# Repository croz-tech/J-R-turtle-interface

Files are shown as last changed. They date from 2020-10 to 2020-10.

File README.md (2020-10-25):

# J-R-turtle-interface
Re-creation of the Jessop-Ralph turtle interface for the BBC Micro range of home computers.

Connects to the BBC Micro user port (20 way IDC) and the turtle via a 15 way D connector.
Requires a +5V stabilised power supply which can be taken from the BBC Micro's aux power output.  However this is often used for disk drives, therefore a seperate power supply can be used.  Interface and turtle are comatible with Acornsoft Logo (using the JESSOP) extension.  It can also be used with DART software or driven directly via user port commands.

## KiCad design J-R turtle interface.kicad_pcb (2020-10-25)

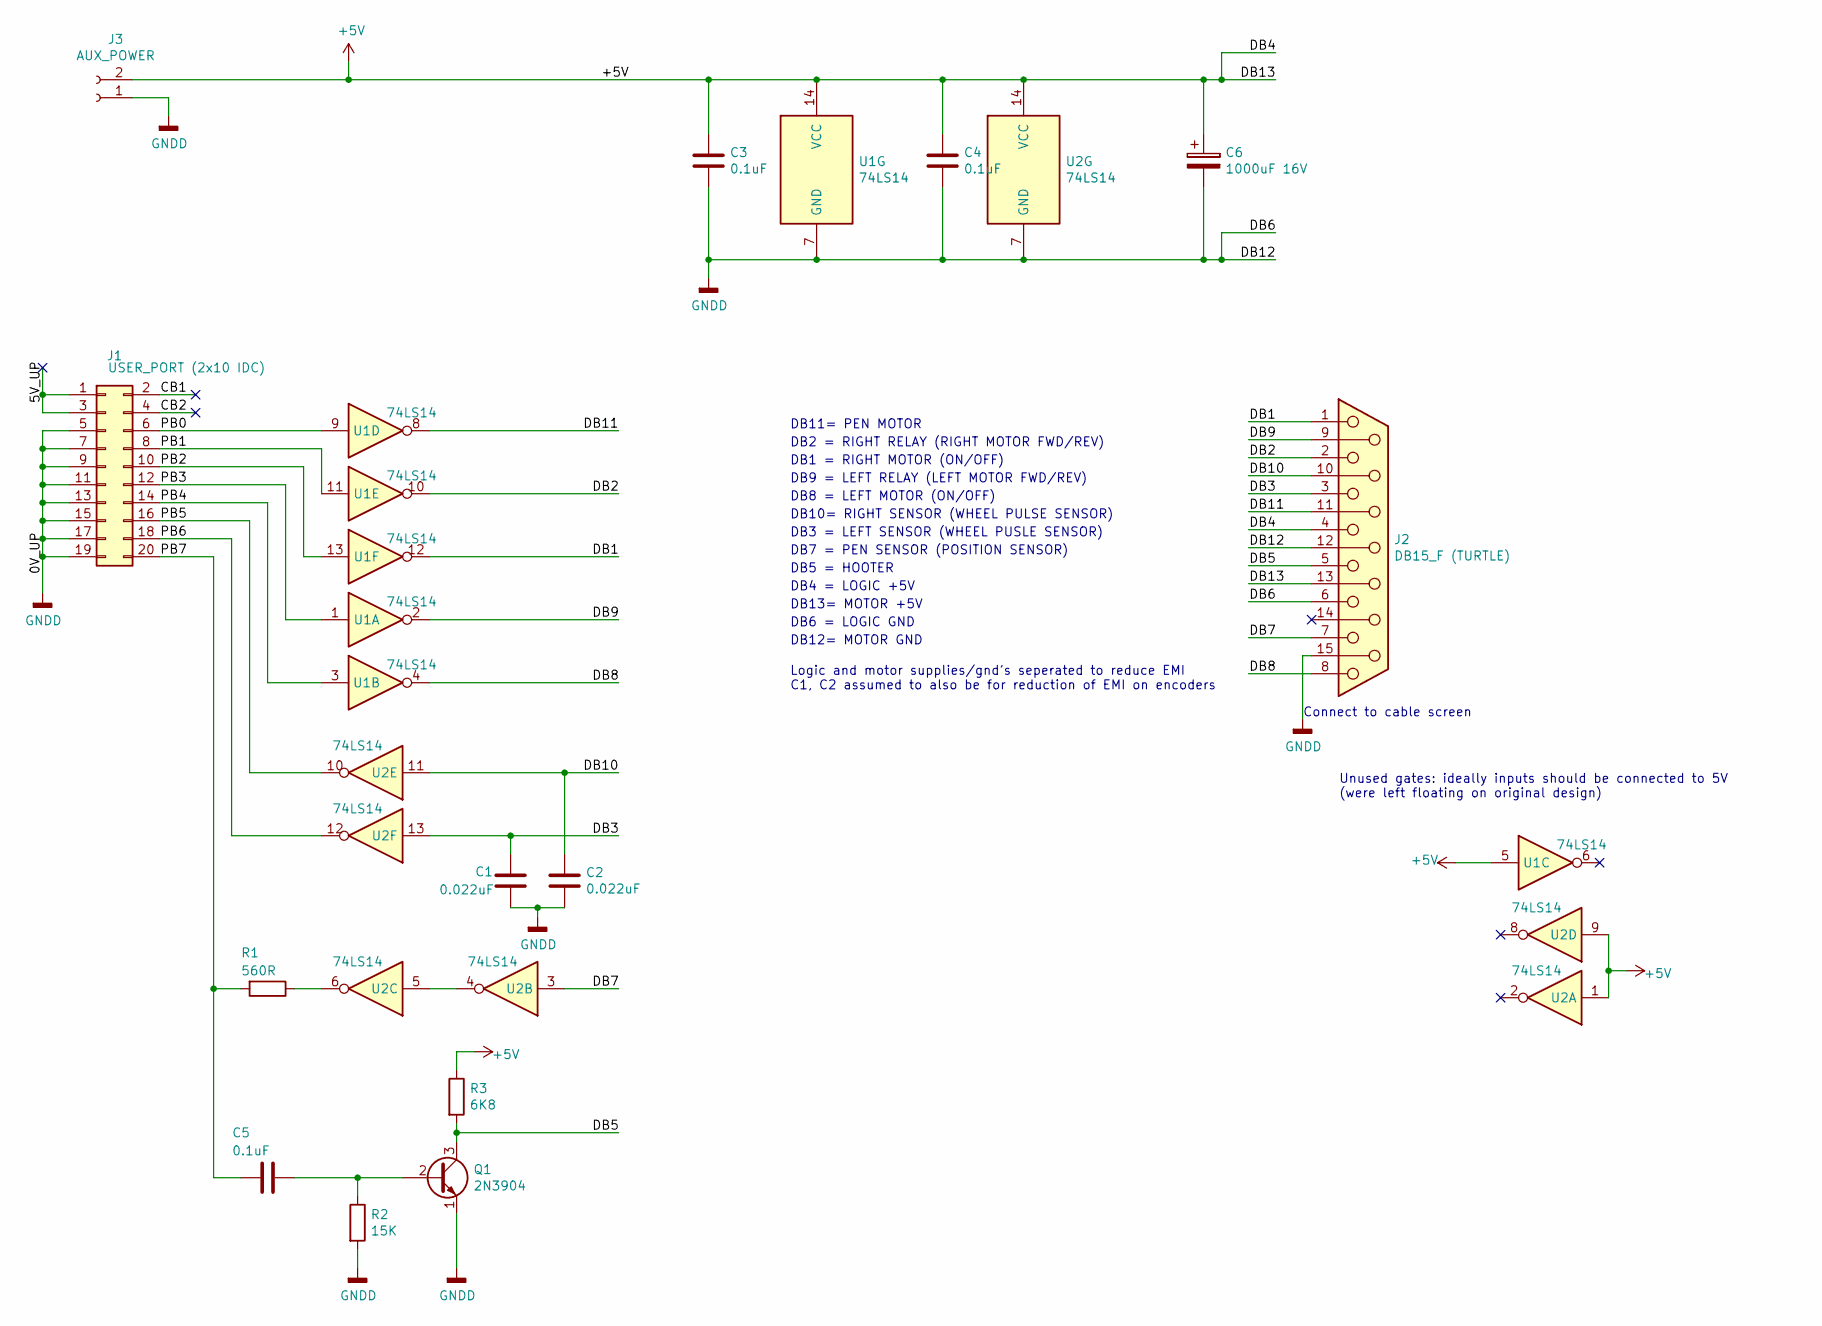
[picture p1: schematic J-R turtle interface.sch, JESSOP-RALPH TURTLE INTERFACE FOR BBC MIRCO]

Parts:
C1, C2: 0.022uF; C_Rect_L7.2mm_W2.5mm_P5.00mm_FKS2_FKP2_MKS2_MKP2
C3, C4, C5: 0.1uF; C_Rect_L7.2mm_W2.5mm_P5.00mm_FKS2_FKP2_MKS2_MKP2
C6: 1000uF 16V; CP_Radial_D10.0mm_P5.00mm
J1: USER_PORT (2x10 IDC); 20W_IDC_TERM
J2: DB15_F (TURTLE); PinHeader_1x15_P2.54mm_Vertical
J3: AUX_POWER; PinHeader_1x02_P2.54mm_Vertical
Q1: 2N3904; TO-92_Inline
R1: 560R; R_Axial_DIN0207_L6.3mm_D2.5mm_P10.16mm_Horizontal
R2: 15K; R_Axial_DIN0207_L6.3mm_D2.5mm_P10.16mm_Horizontal
R3: 6K8; R_Axial_DIN0207_L6.3mm_D2.5mm_P10.16mm_Horizontal
U1, U2: 74LS14; DIP-14_W7.62mm

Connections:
+5V: C3.1, C4.1, C6.1, J2.4, J2.13, J3.2, R3.1, U1.5, U1.14 (VCC), U2.1, U2.9, U2.14 (VCC)
/5V_UP: J1.1, J1.3
/CB1: J1.2
/CB2: J1.4
/DB1: J2.1, U1.12
/DB2: J2.2, U1.10
/DB3: C1.1, J2.3, U2.13
/DB5: J2.5, Q1.3 (C), R3.2
/DB7: J2.7, U2.3
/DB8: J2.8, U1.4
/DB9: J2.9, U1.2
/DB10: C2.1, J2.10, U2.11
/DB11: J2.11 (P111), U1.8
/PB0: J1.6, U1.9
/PB1: J1.8, U1.11
/PB2: J1.10, U1.13
/PB3: J1.12, U1.1
/PB4: J1.14, U1.3
/PB5: J1.16, U2.10
/PB6: J1.18, U2.12
/PB7: C5.2, J1.20, R1.2
GNDD: C1.2, C2.2, C3.2, C4.2, C6.2, J1.5, J1.7, J1.9, J1.11, J1.13, J1.15, J1.17, J1.19, J2.6, J2.12, J2.15, J3.1, Q1.1 (E), R2.2, U1.7 (GND), U2.7 (GND)
unnamed: C5.1, Q1.2 (B), R2.1
unnamed: R1.1, U2.6
unnamed: U2.4, U2.5

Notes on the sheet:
Unused gates: ideally inputs should be connected to 5V (were left floating on original design)
DB11= PEN MOTOR
DB2 = RIGHT RELAY (RIGHT MOTOR FWD/REV)
DB1 = RIGHT MOTOR (ON/OFF)
DB9 = LEFT RELAY (LEFT MOTOR FWD/REV)
DB8 = LEFT MOTOR (ON/OFF)
DB10= RIGHT SENSOR (WHEEL PULSE SENSOR)
DB3 = LEFT SENSOR (WHEEL PUSLE SENSOR)
DB7 = PEN SENSOR (POSITION SENSOR)
DB5 = HOOTER
DB4 = LOGIC +5V
DB13= MOTOR +5V
DB6 = LOGIC GND
DB12= MOTOR GND
Logic and motor supplies/gnd’s seperated to reduce EMI C1, C2 assumed to also be for reduction of EMI on encoders
Connect to cable screen

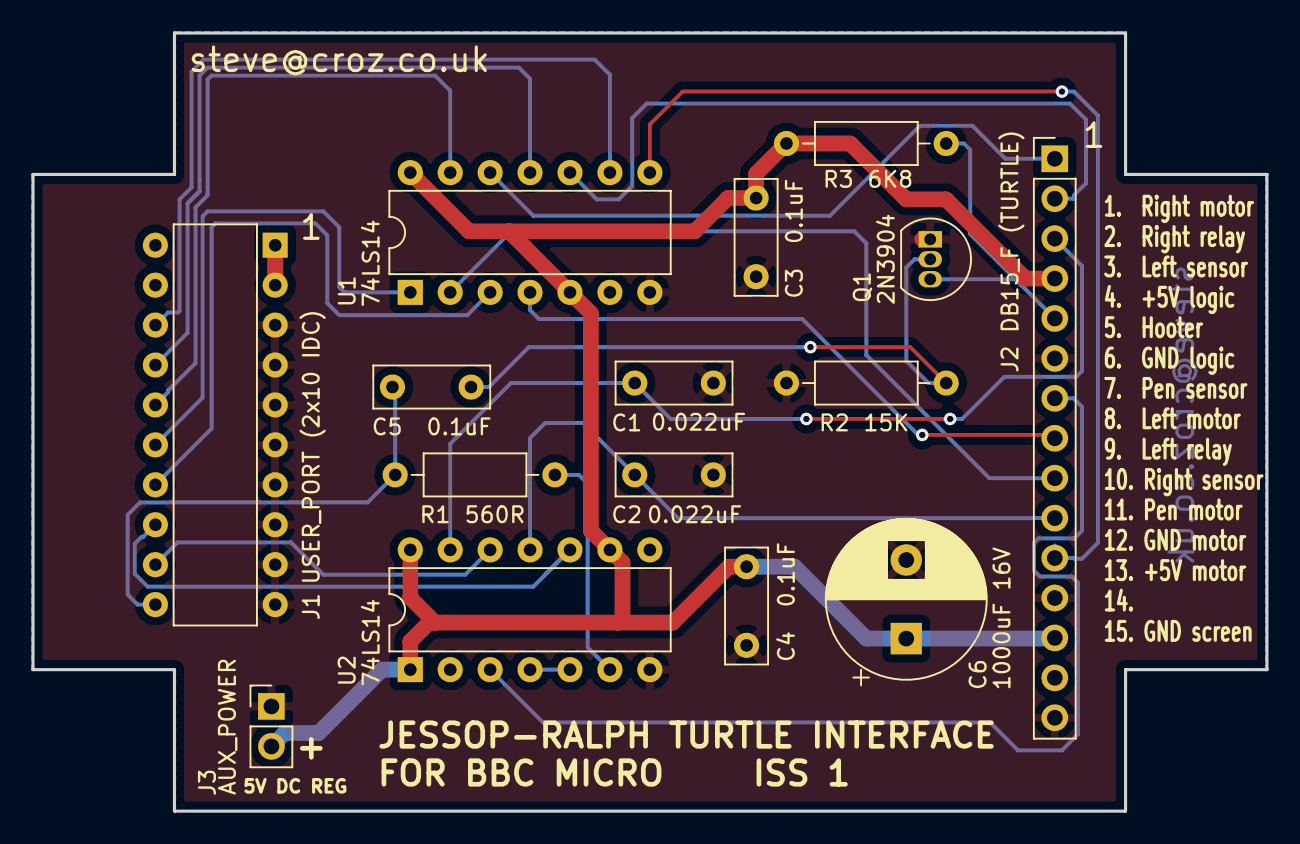
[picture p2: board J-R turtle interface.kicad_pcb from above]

Board: 2 copper layers, 78.5 x 49.5 mm, 15 parts (0 on the bottom side), 23 nets.
